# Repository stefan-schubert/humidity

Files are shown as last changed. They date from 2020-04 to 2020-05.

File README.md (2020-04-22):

# Humidity Monitoring Solution

The intention of the project is to monitor a ceiling cavity for critical humidity. This ceiling cavity is far away from any wlan hotspot. For that reason the system is divided in two units connected with RS485. The communication protocol used on top of RS485 is [PJON](https://www.pjon.org/). The sensor unit has a connection to 3 sensor pairs through I2C bus. The control unit has a buzzer, a display and a button. If humidity is to high the buzzer is activated until a normal value is reached again. The button deactivates the buzzer in the case of an error or enables or disables the display. The dispalay is automatically disabled after 10 minutes inactivity. For historical data recording and alerting the sensor data is submitted to [ubidots](https://ubidots.com/) through a MQTT connection connected over a wlan access point.

Take a look at the [photos](photos/)!

## Wiring

Sensor unit and control unit are connect through RS485 (A+, B+, GND connected with a cat. 5 patch cable wires).

### Sensor Unit

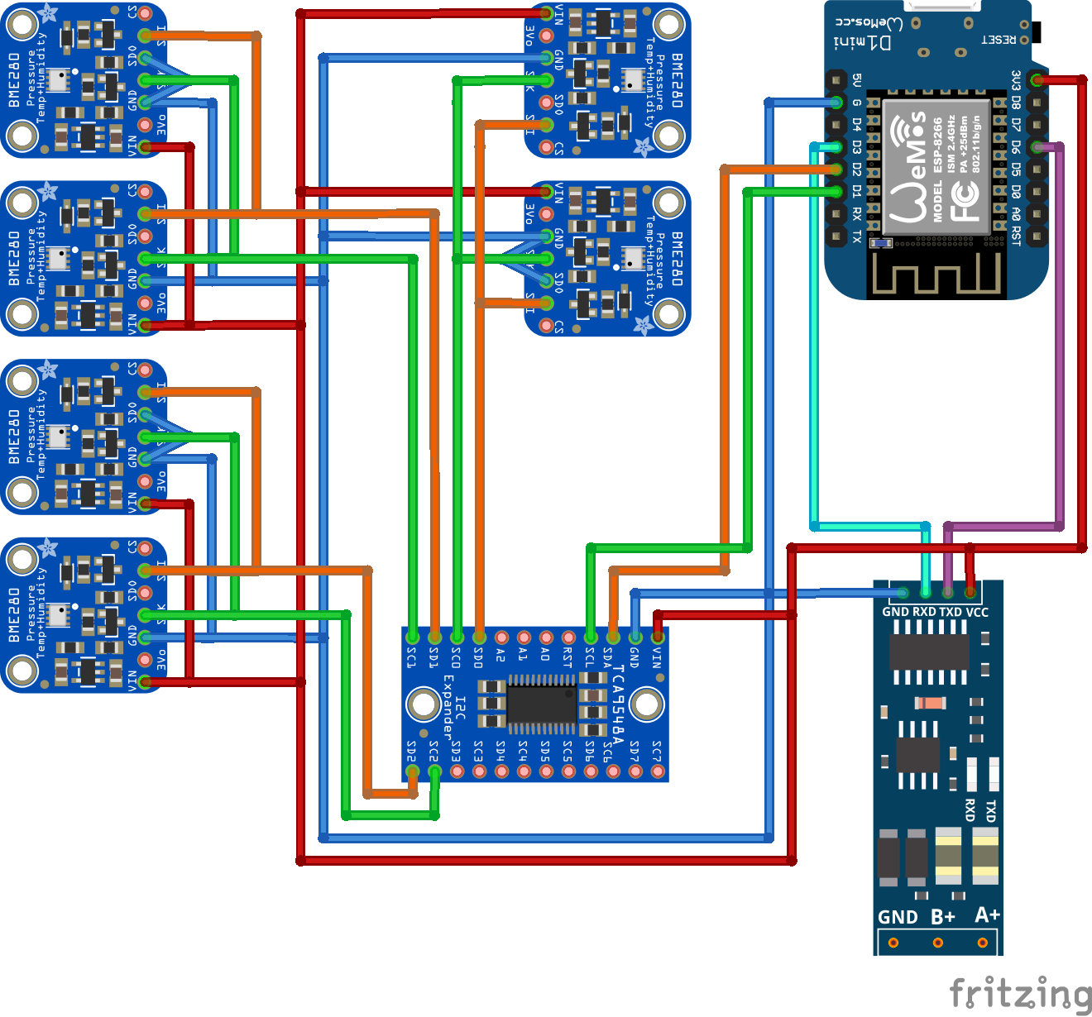
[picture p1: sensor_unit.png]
Sensor Unit


__Hardware Components__
* [Wemos D1 mini](https://www.wemos.cc/en/latest/d1/d1_mini.html)
* [TCA9548A 8-Channel I2C Switch](http://www.ti.com/lit/ds/symlink/tca9548a.pdf)
* [BME280 Pressure Module](https://startingelectronics.org/pinout/GY-BMP280-pressure-sensor-module/) 
  * Tutorials: [[1](https://startingelectronics.org/tutorials/arduino/modules/pressure-sensor/)] [[2](https://randomnerdtutorials.com/esp8266-bme280-arduino-ide/)] [[3](https://www.bluedot.space/tutorials/connect-two-bme280-on-i2c-bus/)] [[4](http://cactus.io/hookups/sensors/barometric/bme280/hookup-arduino-to-multiple-bme280-barometric-pressure-sensors)]
* [TTL RS485 Adapter](https://www.makershop.de/module/kommunikation-module/ttl-rs485-adapter/)
  * [Alternative](https://www.welectron.com/Waveshare-4777-RS485-Board-33V)

### Control Unit

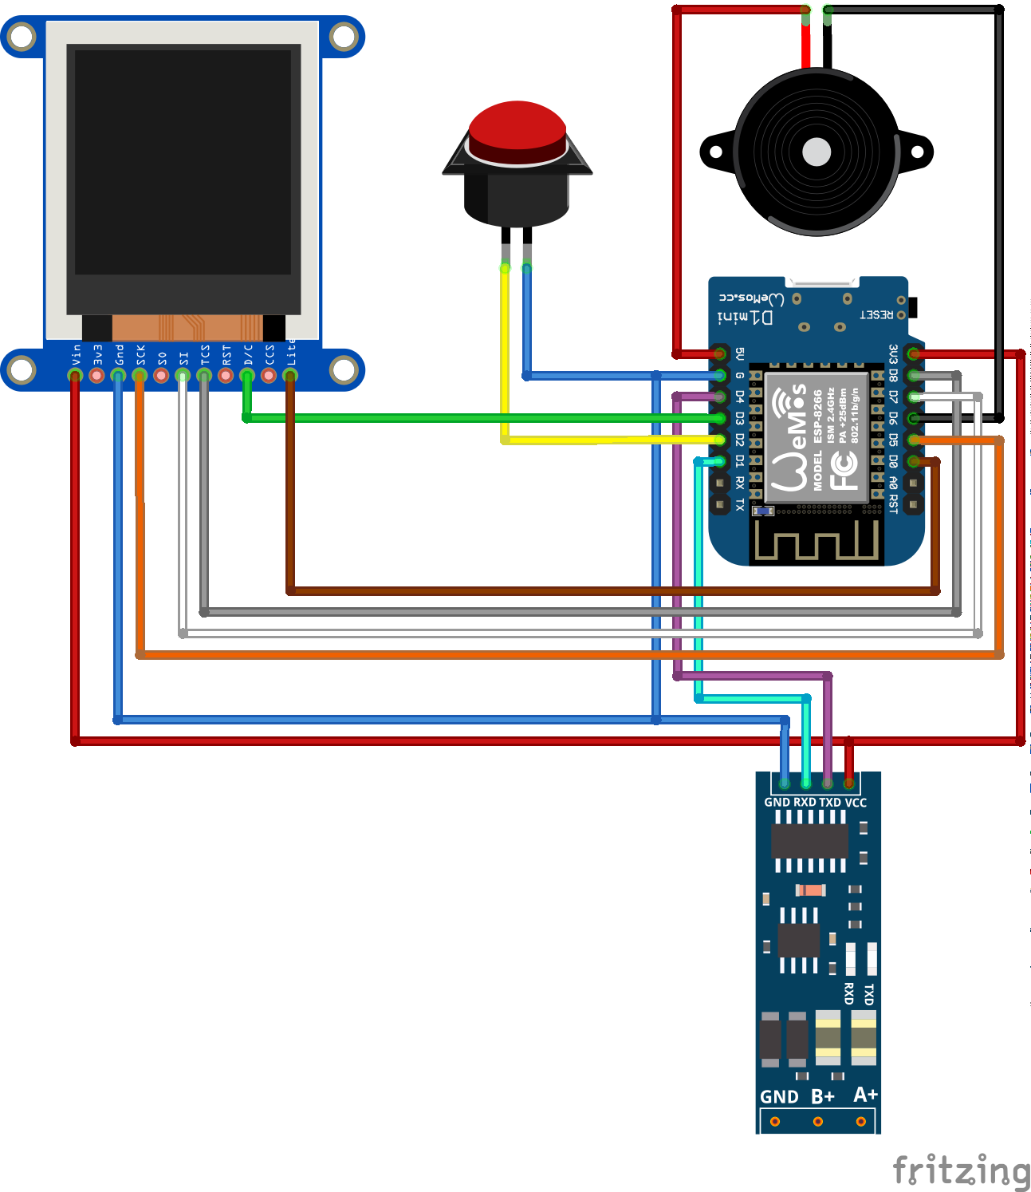
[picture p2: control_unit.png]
Control Unit


__Hardware Components__
* [WEMOS D1 mini](https://www.wemos.cc/en/latest/d1/d1_mini.html)
* [WEMOS TFT 1.4 Shield](https://www.wemos.cc/en/latest/d1_mini_shiled/tft_1_4.html)
* [WEMOS Buzzer Shield](https://www.wemos.cc/en/latest/d1_mini_shiled/buzzer.html)
* [TTL RS485 Adapter](https://www.makershop.de/module/kommunikation-module/ttl-rs485-adapter/)

## Libraries
* WEMOS D1 mini (ESP8266)
  * [5V tolerant?](https://www.ba0sh1.com/blog/2016/08/03/is-esp8266-io-really-5v-tolerant/)
  * Tutorials/Guides:
    * PINs: [[1](https://randomnerdtutorials.com/esp8266-pinout-reference-gpios/)] [[2](http://esp8266-server.de/wemos.html#Pinbelegung)]
    * [Safe Restart](https://github.com/esp8266/Arduino/issues/1722)
    * [WiFi](https://arduino-esp8266.readthedocs.io/en/latest/esp8266wifi/readme.html)
        * WPS [[1](https://www.az-delivery.de/blogs/azdelivery-blog-fur-arduino-und-raspberry-pi/wps-mit-dem-esp8266)] [[2](https://gist.github.com/copa2/fcc718c6549721c210d614a325271389)]
        * [MQTT Client](https://github.com/knolleary/pubsubclient)
        * [Cloud Storage Ubidots](https://ubidots.com/docs/hw/#mqtt)
    * ([DeepSleep](https://randomnerdtutorials.com/esp8266-deep-sleep-with-arduino-ide/))
* BME280 through I2C
    * [BME](https://github.com/finitespace/BME280)
    * [I2C](https://github.com/pasko-zh/brzo_i2c) (Fast Software BitBang written in assembly!)
        * [Interesting facts about I2C](https://www.i2c-bus.org/i2c-primer/analysing-obscure-problems/blocked-bus/)
* TFT
  * [Adafruit-ST7735-Library](https://github.com/adafruit/Adafruit-ST7735-Library/)
  * [U8g2_for_Adafruit_GFX](https://github.com/olikraus/U8g2_for_Adafruit_GFX)
    * [generate fonts](https://github.com/olikraus/u8g2/blob/master/doc/faq.txt#L179)
    * [generate icons](https://github.com/olikraus/u8g2/blob/master/tools/font/png2bdf/test/do_iconic.sh)
  * Examples
    * [Shield](https://github.com/wemos/D1_mini_Examples/tree/master/examples/04.Shields/TFT_1.4_Shield)
    * [Generate Colors](http://www.barth-dev.de/online/rgb565-color-picker/)
* RS485
  * no special library needed
  * Tutorials: [[1](https://maker.pro/arduino/tutorial/creating-long-distance-serial-communication-using-an-arduino-and-an-rs-485-module)] [[2](https://create.arduino.cc/projecthub/philippedc/arduino-esp8266-rs485-modbus-anemometer-45f1d8)] [[3](https://www.hackster.io/philippedc/arduino-esp8266-rs485-modbus-anemometer-45f1d8)] [[4](https://microcontrollerelectronics.com/sn75176-rs485-communications-between-two-arduinos/)] [[5](https://arduinoinfo.mywikis.net/wiki/SoftwareSerialRS485Example)]
  * [PJON](https://www.pjon.org) ([Github](https://github.com/gioblu/PJON)) as network protocol
    * Examples: [[1](https://github.com/gioblu/PJON/tree/master/src/strategies/ThroughSerialAsync)] [[2](https://www.pjon.org/data-reception.php)]
* Button
    * no special library needed
    * Tutorial: [[1](https://hikro.de/arduino-taster-als-schalter-programmieren)] [[2](https://www.arduino.cc/reference/en/language/functions/external-interrupts/attachinterrupt/)]

## Other sources
* [Fritzing parts](https://github.com/Warlib1975/Fritzing-parts)

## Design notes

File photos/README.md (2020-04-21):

# Photos

## Sensor Unit

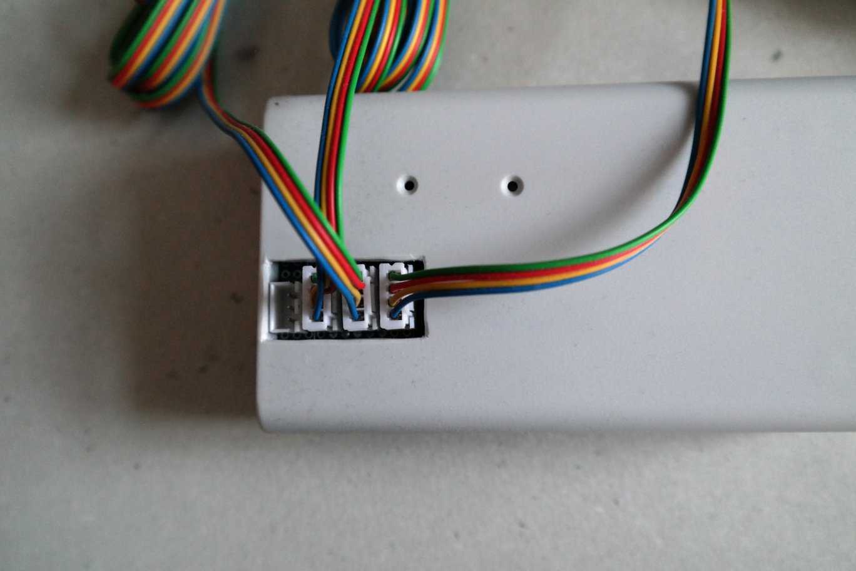
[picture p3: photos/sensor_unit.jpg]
sensor_unit


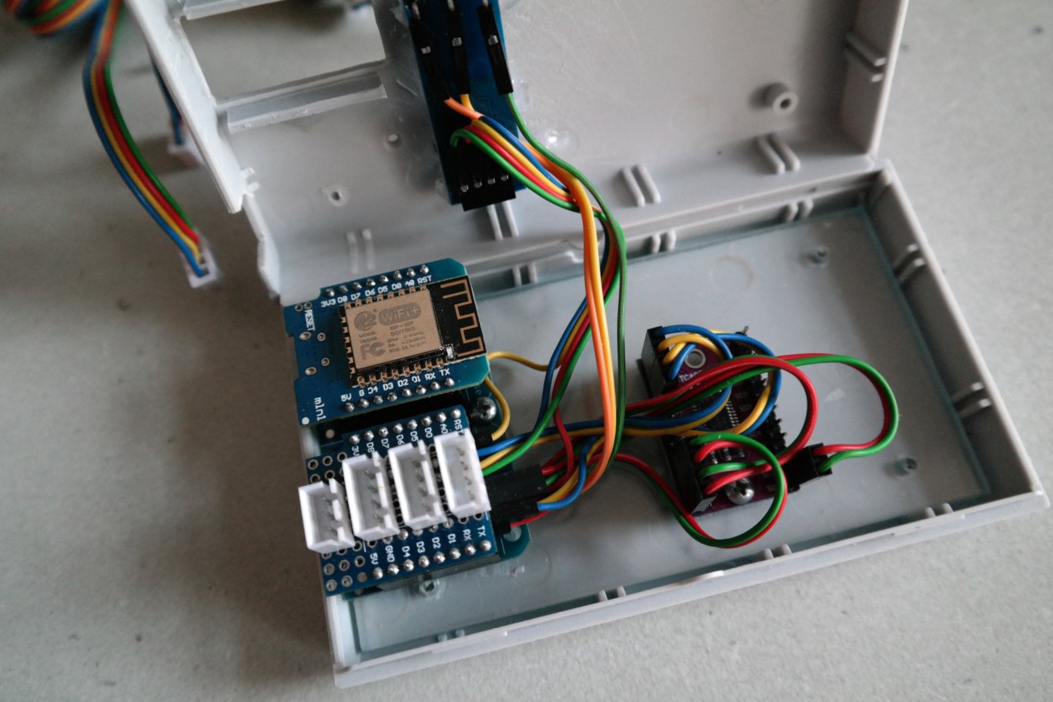
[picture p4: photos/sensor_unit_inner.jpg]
sensor_unit_inner


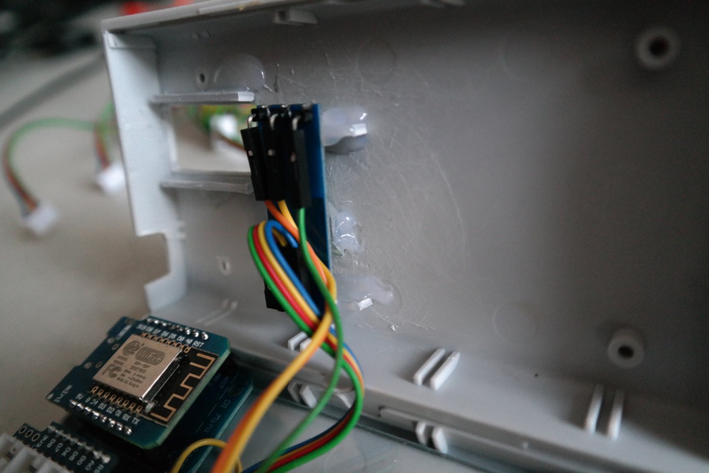
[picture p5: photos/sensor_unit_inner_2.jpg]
sensor_unit_inner_2


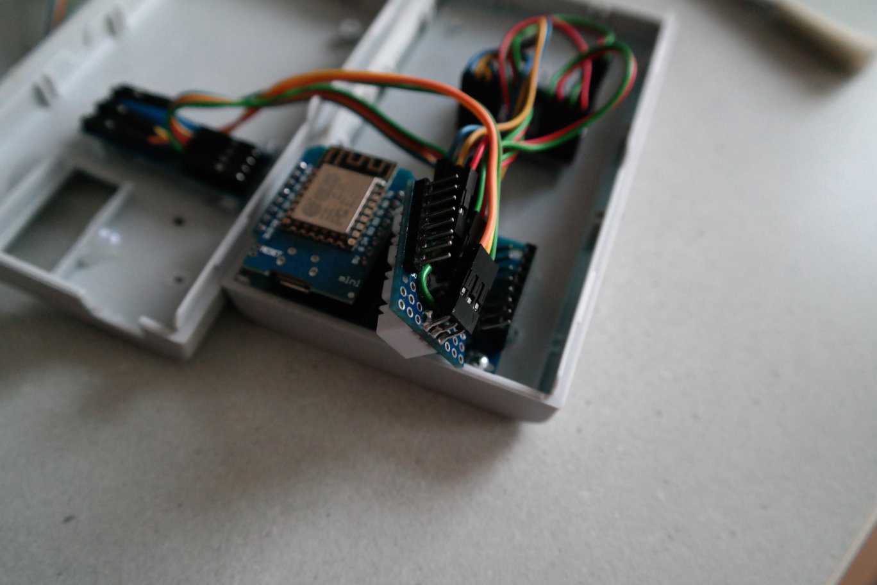
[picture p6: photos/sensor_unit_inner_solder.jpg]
sensor_unit_inner_solder


## Sensors

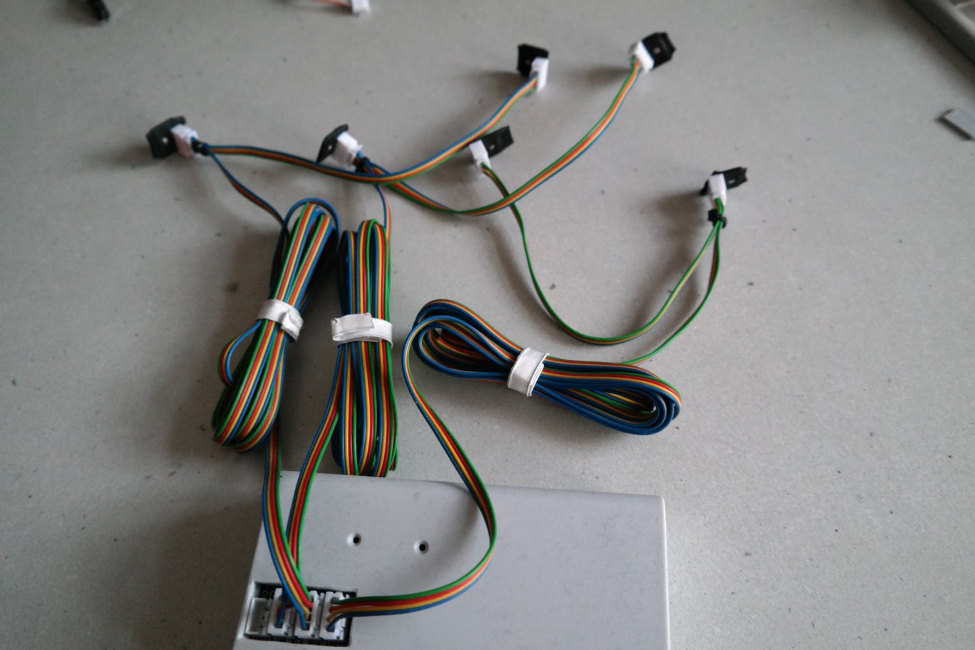
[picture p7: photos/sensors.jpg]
sensors


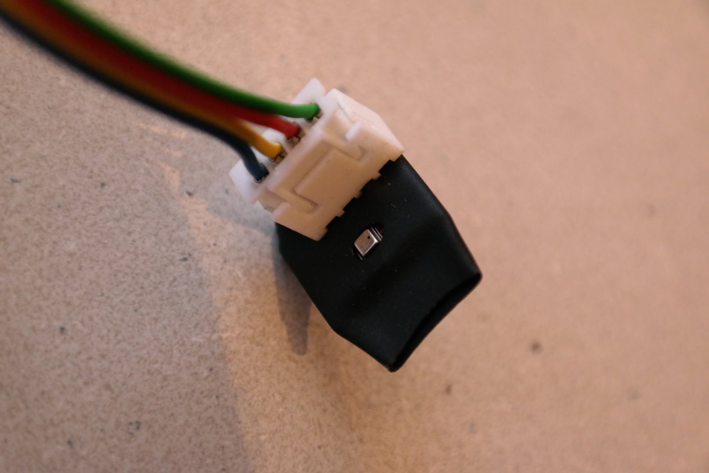
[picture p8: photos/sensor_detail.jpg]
sensor_detail


## Control Unit

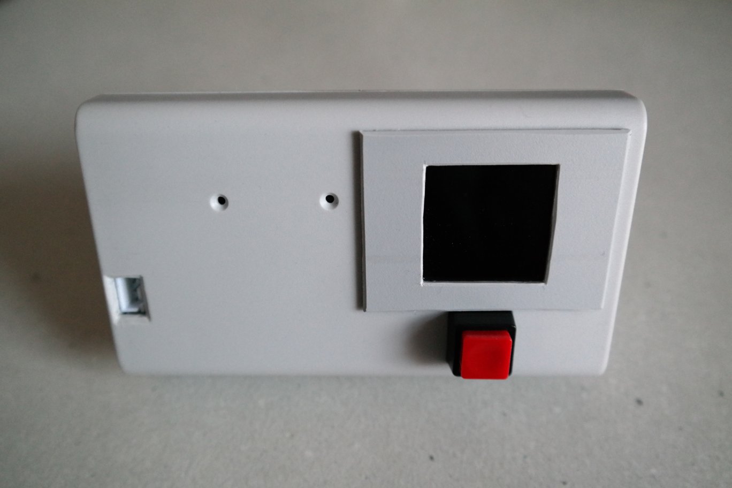
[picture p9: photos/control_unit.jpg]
control_unit


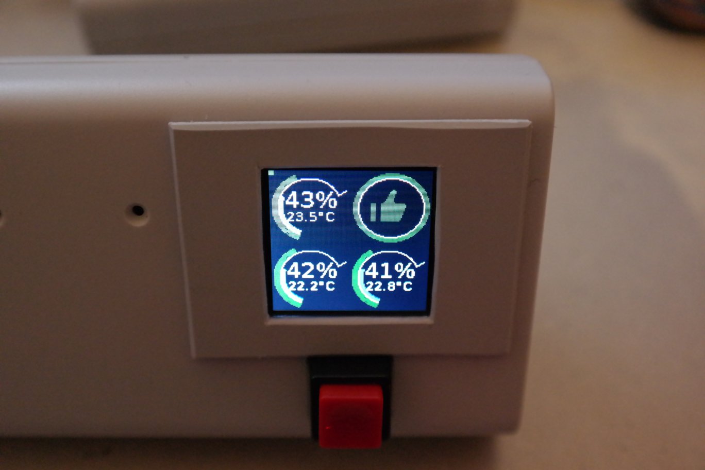
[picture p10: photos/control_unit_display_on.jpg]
control_unit_display_on


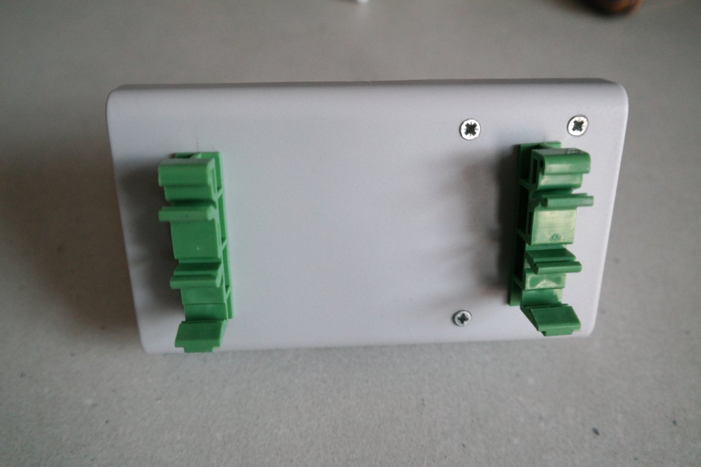
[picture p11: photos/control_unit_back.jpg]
control_unit_back


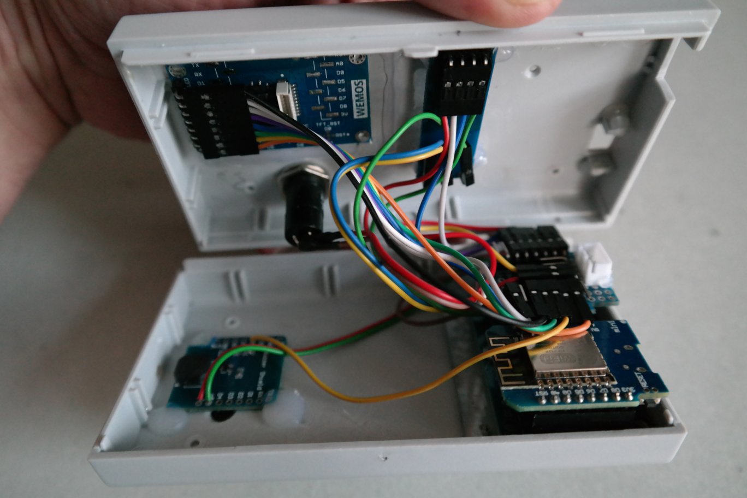
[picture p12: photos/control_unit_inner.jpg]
control_unit_inner


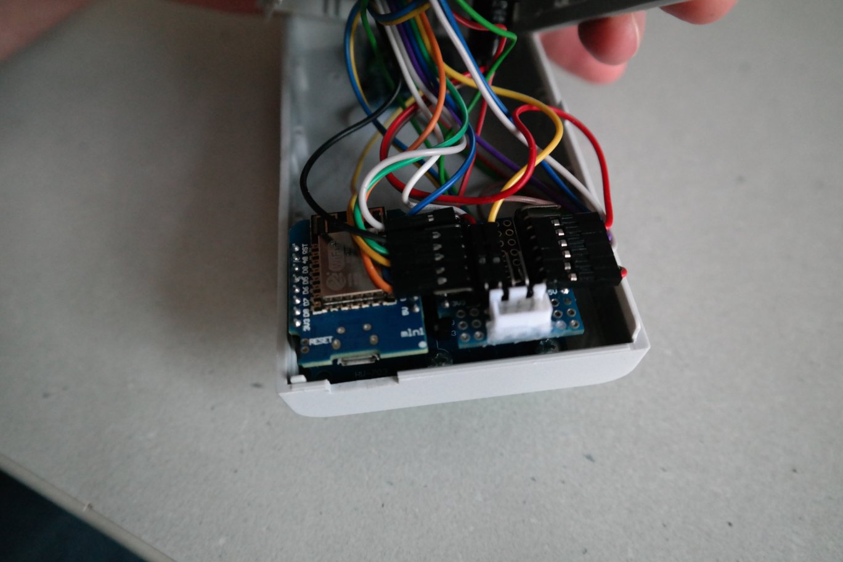
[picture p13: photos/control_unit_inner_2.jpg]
control_unit_inner_2


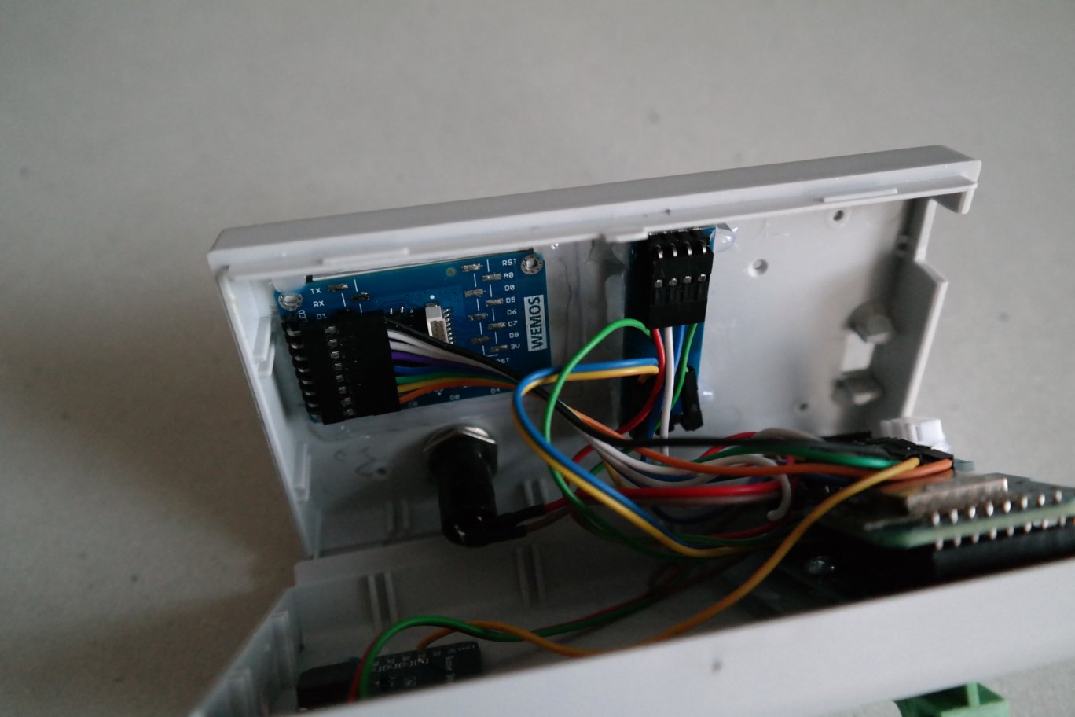
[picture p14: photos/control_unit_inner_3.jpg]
control_unit_inner_3


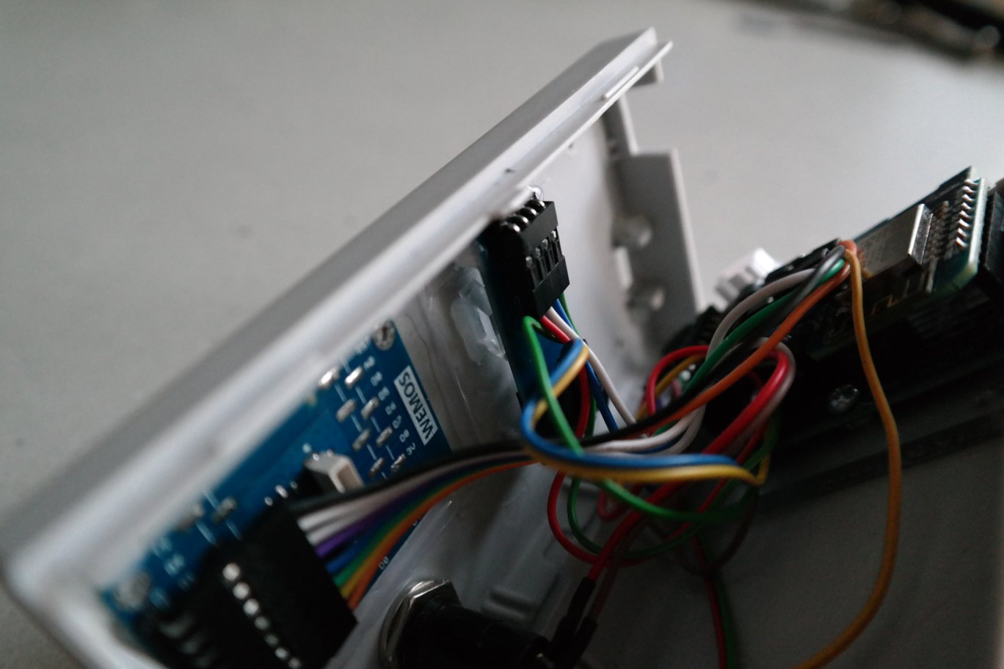
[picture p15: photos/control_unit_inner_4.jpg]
control_unit_inner_4


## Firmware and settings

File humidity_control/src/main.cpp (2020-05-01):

#define PJON_PACKET_MAX_LENGTH 32

#include <config.h>
#include <fonts.h>
#include <Arduino.h>
#include <ESP8266WiFi.h>
#include <time.h>
#include "SoftwareSerial.h"
#include "Wire.h"
#include "PJON.h"
#include "SPI.h"
#include "Adafruit_GFX.h"
#include "Adafruit_ST7735.h"
#include "U8g2_for_Adafruit_GFX.h"
#include "PubSubClient.h"

// DEBUG flag
// #define DEBUG

// pin config
#define RX_PIN D1
#define TX_PIN D4
#define ID 45
#define BUZZER_PIN D6
#define BUTTON_PIN D2
#define TFT_RST -1
#define TFT_CS D8
#define TFT_DC D3
#define TFT_LED D0

// colors
#define GREEN 0x34C0
#define YELLOW 0xFE60
#define RED 0xC980
#define BLUE 0x5E1B

// ubidots
#define SERVER "industrial.api.ubidots.com"
#define SERVER_PORT 8883

// constants
const unsigned int MAX_HUMIDITY = 70;                  // 70.00%
const unsigned int WARN_HUMIDITY = 50;                 // 50.00 %
const unsigned long MAX_AGE = 60000;                   // 1min
const unsigned long MAX_AGE_CLOUD = 300000;            // 5min
const unsigned long DEBOUNCE = 20;                     // 20ms
const unsigned long MAX_DISPLAY_ACTIVE = 600000;       // 10min
const unsigned long MAX_DISCONNECT_TIME = 600000;      // 10min
const unsigned long MAX_MQTT_DISCONNECT_TIME = 300000; // 5min
const uint8_t MAX_WIRES = 3;                           // max 3 sensor pairs
const unsigned int WARN_ANGLE = 110 + 320 * ((float)WARN_HUMIDITY / 100.0f);
const unsigned int ERROR_ANGLE = 110 + 320 * ((float)MAX_HUMIDITY / 100.0f);
// ca file
static const char *ca1 PROGMEM = "-----BEGIN CERTIFICATE-----\nMIIFazCCA1OgAwIBAgIRAIIQz7DSQONZRGPgu2OCiwAwDQYJKoZIhvcNAQELBQAw\nTzELMAkGA1UEBhMCVVMxKTAnBgNVBAoTIEludGVybmV0IFNlY3VyaXR5IFJlc2Vh\ncmNoIEdyb3VwMRUwEwYDVQQDEwxJU1JHIFJvb3QgWDEwHhcNMTUwNjA0MTEwNDM4\nWhcNMzUwNjA0MTEwNDM4WjBPMQswCQYDVQQGEwJVUzEpMCcGA1UEChMgSW50ZXJu\nZXQgU2VjdXJpdHkgUmVzZWFyY2ggR3JvdXAxFTATBgNVBAMTDElTUkcgUm9vdCBY\nMTCCAiIwDQYJKoZIhvcNAQEBBQADggIPADCCAgoCggIBAK3oJHP0FDfzm54rVygc\nh77ct984kIxuPOZXoHj3dcKi/vVqbvYATyjb3miGbESTtrFj/RQSa78f0uoxmyF+\n0TM8ukj13Xnfs7j/EvEhmkvBioZxaUpmZmyPfjxwv60pIgbz5MDmgK7iS4+3mX6U\nA5/TR5d8mUgjU+g4rk8Kb4Mu0UlXjIB0ttov0DiNewNwIRt18jA8+o+u3dpjq+sW\nT8KOEUt+zwvo/7V3LvSye0rgTBIlDHCNAymg4VMk7BPZ7hm/ELNKjD+Jo2FR3qyH\nB5T0Y3HsLuJvW5iB4YlcNHlsdu87kGJ55tukmi8mxdAQ4Q7e2RCOFvu396j3x+UC\nB5iPNgiV5+I3lg02dZ77DnKxHZu8A/lJBdiB3QW0KtZB6awBdpUKD9jf1b0SHzUv\nKBds0pjBqAlkd25HN7rOrFleaJ1/ctaJxQZBKT5ZPt0m9STJEadao0xAH0ahmbWn\nOlFuhjuefXKnEgV4We0+UXgVCwOPjdAvBbI+e0ocS3MFEvzG6uBQE3xDk3SzynTn\njh8BCNAw1FtxNrQHusEwMFxIt4I7mKZ9YIqioymCzLq9gwQbooMDQaHWBfEbwrbw\nqHyGO0aoSCqI3Haadr8faqU9GY/rOPNk3sgrDQoo//fb4hVC1CLQJ13hef4Y53CI\nrU7m2Ys6xt0nUW7/vGT1M0NPAgMBAAGjQjBAMA4GA1UdDwEB/wQEAwIBBjAPBgNV\nHRMBAf8EBTADAQH/MB0GA1UdDgQWBBR5tFnme7bl5AFzgAiIyBpY9umbbjANBgkq\nhkiG9w0BAQsFAAOCAgEAVR9YqbyyqFDQDLHYGmkgJykIrGF1XIpu+ILlaS/V9lZL\nubhzEFnTIZd+50xx+7LSYK05qAvqFyFWhfFQDlnrzuBZ6brJFe+GnY+EgPbk6ZGQ\n3BebYhtF8GaV0nxvwuo77x/Py9auJ/GpsMiu/X1+mvoiBOv/2X/qkSsisRcOj/KK\nNFtY2PwByVS5uCbMiogziUwthDyC3+6WVwW6LLv3xLfHTjuCvjHIInNzktHCgKQ5\nORAzI4JMPJ+GslWYHb4phowim57iaztXOoJwTdwJx4nLCgdNbOhdjsnvzqvHu7Ur\nTkXWStAmzOVyyghqpZXjFaH3pO3JLF+l+/+sKAIuvtd7u+Nxe5AW0wdeRlN8NwdC\njNPElpzVmbUq4JUagEiuTDkHzsxHpFKVK7q4+63SM1N95R1NbdWhscdCb+ZAJzVc\noyi3B43njTOQ5yOf+1CceWxG1bQVs5ZufpsMljq4Ui0/1lvh+wjChP4kqKOJ2qxq\n4RgqsahDYVvTH9w7jXbyLeiNdd8XM2w9U/t7y0Ff/9yi0GE44Za4rF2LN9d11TPA\nmRGunUHBcnWEvgJBQl9nJEiU0Zsnvgc/ubhPgXRR4Xq37Z0j4r7g1SgEEzwxA57d\nemyPxgcYxn/eR44/KJ4EBs+lVDR3veyJm+kXQ99b21/+jh5Xos1AnX5iItreGCc=\n-----END CERTIFICATE-----\n";
static const char *ca2 PROGMEM = "-----BEGIN CERTIFICATE-----\nMIIDSjCCAjKgAwIBAgIQRK+wgNajJ7qJMDmGLvhAazANBgkqhkiG9w0BAQUFADA/\nMSQwIgYDVQQKExtEaWdpdGFsIFNpZ25hdHVyZSBUcnVzdCBDby4xFzAVBgNVBAMT\nDkRTVCBSb290IENBIFgzMB4XDTAwMDkzMDIxMTIxOVoXDTIxMDkzMDE0MDExNVow\nPzEkMCIGA1UEChMbRGlnaXRhbCBTaWduYXR1cmUgVHJ1c3QgQ28uMRcwFQYDVQQD\nEw5EU1QgUm9vdCBDQSBYMzCCASIwDQYJKoZIhvcNAQEBBQADggEPADCCAQoCggEB\nAN+v6ZdQCINXtMxiZfaQguzH0yxrMMpb7NnDfcdAwRgUi+DoM3ZJKuM/IUmTrE4O\nrz5Iy2Xu/NMhD2XSKtkyj4zl93ewEnu1lcCJo6m67XMuegwGMoOifooUMM0RoOEq\nOLl5CjH9UL2AZd+3UWODyOKIYepLYYHsUmu5ouJLGiifSKOeDNoJjj4XLh7dIN9b\nxiqKqy69cK3FCxolkHRyxXtqqzTWMIn/5WgTe1QLyNau7Fqckh49ZLOMxt+/yUFw\n7BZy1SbsOFU5Q9D8/RhcQPGX69Wam40dutolucbY38EVAjqr2m7xPi71XAicPNaD\naeQQmxkqtilX4+U9m5/wAl0CAwEAAaNCMEAwDwYDVR0TAQH/BAUwAwEB/zAOBgNV\nHQ8BAf8EBAMCAQYwHQYDVR0OBBYEFMSnsaR7LHH62+FLkHX/xBVghYkQMA0GCSqG\nSIb3DQEBBQUAA4IBAQCjGiybFwBcqR7uKGY3Or+Dxz9LwwmglSBd49lZRNI+DT69\nikugdB/OEIKcdBodfpga3csTS7MgROSR6cz8faXbauX+5v3gTt23ADq1cEmv8uXr\nAvHRAosZy5Q6XkjEGB5YGV8eAlrwDPGxrancWYaLbumR9YbK+rlmM6pZW87ipxZz\nR8srzJmwN0jP41ZL9c8PDHIyh8bwRLtTcm1D9SZImlJnt1ir/md2cXjbDaJWFBM5\nJDGFoqgCWjBH4d1QB7wCCZAA62RjYJsWvIjJEubSfZGL+T0yjWW06XyxV3bqxbYo\nOb8VZRzI9neWagqNdwvYkQsEjgfbKbYK7p2CNTUQ\n-----END CERTIFICATE-----\n";
BearSSL::X509List x509;

// display
Adafruit_ST7735 tft = Adafruit_ST7735(TFT_CS, TFT_DC, TFT_RST);
U8G2_FOR_ADAFRUIT_GFX u8g2;
// serial port for PJON
SoftwareSerial port;
PJON<ThroughSerialAsync> bus(ID);
// secure wifi connection client
WiFiClientSecure client;
// client
PubSubClient mqtt(SERVER, SERVER_PORT, client);

// PJON data structure
struct sensor
{
  uint16_t humidity;
  uint16_t temperature;
  bool connected_0;
  bool connected_1;
};
struct sensor_record
{
  sensor sensors[MAX_WIRES];
};
// status of system
enum status
{
  ERROR,
  WARN,
  NORMAL,
  OUTDATED,
  NONE,
  INIT
};
// cache data structure
struct cache_entry
{
  bool fresh;
  bool value_available;
  uint16_t humidity;
  double temperature;
};
struct cache
{
  cache_entry entries[MAX_WIRES];
};

// timers
unsigned long last_time_button_pressed = millis();
unsigned long last_time_payload_recieved = millis();
unsigned long last_time_display_active = millis();
unsigned long last_time_data_submitted = millis();
unsigned long last_time_tried_to_reconnect = 0;
// flags
volatile bool data_cleared = false;
volatile bool buttonPressed = false;
volatile bool buzzer_active = false;
volatile bool error_active = false;
volatile bool display_active = true;
bool initial_connection_status = false;
// status
status last_status = INIT;
// record
sensor_record record = {.sensors = {{.humidity = 0, .temperature = 0, .connected_0 = false, .connected_1 = false}, {.humidity = 0, .temperature = 0, .connected_0 = false, .connected_1 = false}, {.humidity = 0, .temperature = 0, .connected_0 = false, .connected_1 = false}}};
// cache
cache cache_instance = {.entries = {{.fresh = true}, {.fresh = true}, {.fresh = true}}};

/**
 * Toggles display on or off.
 * 
 * @param on_off display state, true == on
 */
void toggleDisplay(bool on_off)
{
  last_time_display_active = millis();
  if (display_active == on_off)
  {
    return;
  }
  display_active = on_off;
  tft.enableDisplay(on_off);
  digitalWrite(TFT_LED, on_off ? HIGH : LOW);
}

/**
 * Draws an arc on given coordinate.
 */
void drawArc(uint16_t x, uint16_t y, int start_angle, int end_angle, uint16_t radius, uint16_t thinkness, uint16_t color)
{
  for (int i = start_angle; i <= end_angle; i++)
  {
    double rad_inner = i * DEG_TO_RAD;
    double rad_outer0 = (i == start_angle ? i : i - 1) * DEG_TO_RAD;
    double rad_outer1 = (i == end_angle ? i : i + 1) * DEG_TO_RAD;
    uint16_t outer_radius = radius + thinkness;
    double x0 = (cos(rad_inner) * radius) + x;
    double y0 = (sin(rad_inner) * radius) + y;
    double x1 = (cos(rad_outer0) * outer_radius) + x;
    double y1 = (sin(rad_outer0) * outer_radius) + y;
    double x2 = (cos(rad_outer1) * outer_radius) + x;
    double y2 = (sin(rad_outer1) * outer_radius) + y;
    tft.drawTriangle(x0, y0, x1, y1, x2, y2, color);
  }
}

/**
 * Draws a gauge at specified coordinate.
 */
void drawGauge(uint16_t x, uint16_t y, sensor *sensor, cache_entry *cache)
{
  // normal 0-50, warn 51-70, error 71-100
  uint16_t h = round((double)sensor->humidity / 100.0);
  h = h < 100 ? h : 100;
  double t = (double)(sensor->temperature / 10) / 10.0;
  t = t < 80.0 ? t : 80.0;
  bool value_available = sensor->connected_0 || sensor->connected_0;
  bool force_update = !cache->value_available && cache->value_available != value_available;
  bool force_reset = !value_available && value_available != cache->value_available;

  // 360-40 = 320
  // draw humidity
  if (cache->fresh || force_update || (h != cache->humidity && value_available))
  {
    uint16_t degrees = round(h * 3.2) + 110;
    if (h > 0 && h <= WARN_HUMIDITY)
    {
      drawArc(x, y, 110, degrees, 26, 4, GREEN);
    }
    else if (h > WARN_HUMIDITY && h <= MAX_HUMIDITY)
    {
      drawArc(x, y, 110, WARN_ANGLE, 26, 4, GREEN);
      drawArc(x, y, WARN_ANGLE + 1, degrees, 26, 4, YELLOW);
    }
    else if (h > MAX_HUMIDITY)
    {
      drawArc(x, y, 110, WARN_ANGLE, 26, 4, GREEN);
      drawArc(x, y, WARN_ANGLE + 1, ERROR_ANGLE, 26, 4, YELLOW);
      drawArc(x, y, ERROR_ANGLE + 1, degrees, 26, 4, RED);
    }
    drawArc(x, y, degrees + (degrees > 0 && degrees < 430 ? 1 : 0), 430, 26, 4, ST7735_BLACK);
    drawArc(x, y, ERROR_ANGLE, ERROR_ANGLE, 25, 7, ST7735_WHITE);
  }
  // reset gauge
  if (force_reset)
  {
    drawArc(x, y, 110, 430, 26, 4, ST7735_BLACK);
    drawArc(x, y, ERROR_ANGLE, ERROR_ANGLE, 25, 7, ST7735_WHITE);
  }

  // draw temperature
  if (cache->fresh || force_update || (t != cache->temperature && value_available))
  {
    uint16_t degrees = round(t * 4) + 110;
    drawArc(x, y, 110, degrees, 22, 2, BLUE);
    drawArc(x, y, degrees + (degrees > 0 && degrees < 430 ? 1 : 0), 430, 22, 2, ST7735_BLACK);
  }
  // reset gauge
  if (force_reset)
  {
    drawArc(x, y, 110, 430, 22, 2, ST7735_BLACK);
  }

  // write numbers
  if (cache->fresh || force_update || force_reset || h != cache->humidity || t != cache->temperature)
  {
    tft.fillCircle(x, y, 21, ST7735_BLACK);
    u8g2.setForegroundColor(ST7735_WHITE);
    char h_string[4] = "--%";
    if (h > 0 && value_available)
    {
      sprintf(h_string, "%3d%%", h);
    }
    u8g2.setFont(dejavu_14);
    u8g2.drawUTF8(x - u8g2.getUTF8Width(h_string) / 2, y, h_string);

    u8g2.setForegroundColor(ST7735_WHITE);
    char t_string[8] = "--°C";
    if (t > 0 && value_available)
    {
      sprintf(t_string, "%3.1f°C", t);
    }
    u8g2.setFont(dejavu_8);
    u8g2.drawUTF8(x - u8g2.getUTF8Width(t_string) / 2, y + 12, t_string);
  }

  // draw max value
  if (cache->fresh)
  {
    drawArc(x, y, 110, 333, 25, 0, ST7735_WHITE);
  }

  // set values in cache
  cache->value_available = value_available;
  cache->fresh = false;
  cache->humidity = h;
  cache->temperature = t;
}

/**
 * Draws a status as icon.
 */
void drawStatus(uint16_t x, uint16_t y, status s, status *last_status)
{
  status last = *last_status;
  if (last != s)
  {
    switch (s)
    {
    case ERROR:
      tft.fillCircle(x, y, 30, RED);
      tft.fillCircle(x, y, 26, ST7735_BLACK);
      tft.drawCircle(x, y, 26, ST7735_WHITE);
      u8g2.setFont(open_iconic_symbols_4x);
      u8g2.setForegroundColor(BLUE);
      u8g2.drawGlyph(x - 16, y + 16, 67);
      break;
    case WARN:
      tft.fillCircle(x, y, 30, YELLOW);
      tft.fillCircle(x, y, 26, ST7735_BLACK);
      tft.drawCircle(x, y, 26, ST7735_WHITE);
      u8g2.setFont(open_iconic_symbols_4x);
      u8g2.setForegroundColor(YELLOW);
      u8g2.drawGlyph(x - 14, y + 14, 66);
      break;
    case NORMAL:
      tft.fillCircle(x, y, 30, GREEN);
      tft.fillCircle(x, y, 26, ST7735_BLACK);
      tft.drawCircle(x, y, 26, ST7735_WHITE);
      u8g2.setFont(open_iconic_symbols_4x);
      u8g2.setForegroundColor(GREEN);
      u8g2.drawGlyph(x - 16, y + 16, 65);
      break;
    case OUTDATED:
      tft.fillCircle(x, y, 30, ST7735_BLACK);
      tft.drawCircle(x, y, 26, ST7735_WHITE);
      u8g2.setFont(open_iconic_symbols_4x);
      u8g2.setForegroundColor(ST7735_WHITE);
      u8g2.drawGlyph(x - 16, y + 16, 64);
      break;
    default:
      tft.fillCircle(x, y, 30, ST7735_BLACK);
      tft.drawCircle(x, y, 26, ST7735_WHITE);
      break;
    }
  }
  *last_status = s;
}

/**
 * Checks record for new status by checking values against configured threshold.
 */
void checkStatusAndDrawValues(sensor_record *record)
{
  last_time_payload_recieved = millis();
  if (data_cleared)
  {
    toggleDisplay(true);
  }
  data_cleared = false;
  uint16_t max_humidity = 0;
  for (uint8_t i = 0; i < MAX_WIRES; i++)
  {
    if (record->sensors[i].humidity > max_humidity)
    {
      max_humidity = record->sensors[i].humidity;
    }
  }
  if (max_humidity > MAX_HUMIDITY * 100 && !error_active)
  {
#ifdef DEBUG
    Serial.println("Humidity to high: Turn on the buzzer!");
#endif
    toggleDisplay(true);
    error_active = true;
    buzzer_active = true;
    tone(BUZZER_PIN, 1480.0);
    drawStatus(96, 32, ERROR, &last_status);
  }
  else if (max_humidity > WARN_HUMIDITY * 100 && max_humidity <= MAX_HUMIDITY * 100)
  {
    noTone(BUZZER_PIN);
    drawStatus(96, 32, WARN, &last_status);
  }
  else if (max_humidity > 0 && max_humidity <= WARN_HUMIDITY * 100)
  {
    noTone(BUZZER_PIN);
    drawStatus(96, 32, NORMAL, &last_status);
  }
  if (error_active && max_humidity <= MAX_HUMIDITY * 100)
  {
    error_active = false;
  }
  drawGauge(32, 32, &record->sensors[0], &cache_instance.entries[0]);
  drawGauge(32, 96, &record->sensors[1], &cache_instance.entries[1]);
  drawGauge(96, 96, &record->sensors[2], &cache_instance.entries[2]);
}

/**
 * Connects MQTT
 */
bool connectMQTT()
{
  // Stop if already connected.
  if (mqtt.connected())
  {
    return true;
  }

#ifdef DEBUG
  Serial.println("Connecting to MQTT... ");
#endif

  bool result = mqtt.connect("humidity_device", TOKEN, "");
  if (!result)
  {
#ifdef DEBUG
    Serial.println(mqtt.state());
    Serial.println("MQTT not connected!");
#endif
    mqtt.disconnect();
    // set connection status
    tft.fillRect(0, 0, 4, 4, YELLOW);
    return false;
  }

#ifdef DEBUG
  Serial.println("MQTT connected!");
#endif

  // set connection status
  tft.fillRect(0, 0, 4, 4, GREEN);
  return true;
}

/**
 * Submits values to mqtt broker.
 */
void submitValues(sensor_record *record)
{
  long current_millis = millis();
  if (initial_connection_status && (current_millis - last_time_data_submitted) > MAX_AGE_CLOUD && mqtt.connected() && mqtt.state() == MQTT_CONNECTED)
  {
    last_time_data_submitted = current_millis;
#ifdef DEBUG
    Serial.println("Submit data!");
#endif

    // build topic and payload
    char payload[50];
    char *payload_ptr = payload;
    bool has_payload = false;
    for (uint8_t i = 0; i < MAX_WIRES; i++)
    {
      if (record->sensors[i].connected_0 || record->sensors[i].connected_1)
      {
        payload_ptr += sprintf(payload_ptr, "%s\"h%d\":%3.2f,\"t%d\":%3.2f", has_payload ? "," : "", i, record->sensors[i].humidity / 100.0, i, record->sensors[i].temperature / 100.0);
        has_payload = true;
      }
    }
    if (has_payload)
    {
      char wrapped[50];
      sprintf(wrapped, "{%s}", payload);
#ifdef DEBUG
      Serial.println(wrapped);
#endif
      // publish data
      mqtt.publish(TOPIC, wrapped);
    }
#ifdef DEBUG
    Serial.printf("Free space: [%d]\n", ESP.getFreeHeap());
#endif
  }
#ifdef DEBUG
  if (mqtt.state() != MQTT_CONNECTED)
  {
    Serial.println("MQTT Connection lost!");
  }
#endif
}

/**
 * Payload handler for PJON.
 */
void payloadHandler(uint8_t *payload, uint16_t length, const PJON_Packet_Info &packet_info)
{
  memcpy(&record, payload, sizeof(record));
  // handler data
  checkStatusAndDrawValues(&record);
  // send data to the cloud
  submitValues(&record);
#ifdef DEBUG
  for (uint8_t i = 0; i < MAX_WIRES; i++)
  {
    Serial.printf("Recieved: hum %u; temp %u; s0 %u; s1 %u\n", record.sensors[i].humidity, record.sensors[i].temperature, record.sensors[i].connected_0, record.sensors[i].connected_1);
  }
#endif
}

/**
 * Error handler for PJON.
 */
void errorHandler(uint8_t code, uint16_t data, void *custom_pointer)
{
  if (code == PJON_CONNECTION_LOST)
  {
    digitalWrite(LED_BUILTIN, HIGH);
#ifdef DEBUG
    Serial.println("Error!");
#endif
  }
}

/**
 * Button interupt handler. 
 * 
 * Turns on display, if display is off and now error is present.
 * If error is present, button pressed deactivates buzzer.
 */
void ICACHE_RAM_ATTR buttonPress()
{
  if ((millis() - last_time_button_pressed) > DEBOUNCE)
  {
    if (buttonPressed == false)
    {
      buttonPressed = true;
      if (!buzzer_active)
      {
        toggleDisplay(!display_active);
      }
      buzzer_active = false;
      noTone(BUZZER_PIN);
    }
    else
    {
      buttonPressed = false;
    }
    last_time_button_pressed = millis();
  }
}

/**
 * Init wifi.
 */
bool initWifi()
{
  WiFi.mode(WIFI_STA);
#ifdef DEBUG
  Serial.printf("Stored SSID: [%s]\n", WiFi.SSID().c_str());
#endif
  if (strlen(WiFi.SSID().c_str()) > 0)
  {
    WiFi.begin(WiFi.SSID().c_str(), WiFi.psk().c_str());
  }
  else
  {
    WiFi.begin(DEFAULT_WLAN_SSID, DEFAULT_WLAN_KEY);
  }
  uint8_t count = 0;
  while (WiFi.status() != WL_CONNECTED && count < 100)
  {
    delay(500);
    count++;
  }

  if (WiFi.status() == WL_CONNECTED)
  {
    return true;
  }
  else
  {
    delay(10000);
    // start wps
    if (WiFi.beginWPSConfig() && WiFi.SSID().length() > 0)
    {
      return true;
    }
    else
    {
      return false;
#ifdef DEBUG
      Serial.println("WPS failed!");
#endif
    }
  }
}

/**
 * Setup system.
 */
void setup()
{
  delay(2000);
#ifdef DEBUG
  Serial.begin(9600);
  Serial.setDebugOutput(true);
#endif

  // setup TFT backlight pin
  pinMode(TFT_LED, OUTPUT);
  digitalWrite(TFT_LED, HIGH);

  // init TFT
  tft.initR(INITR_144GREENTAB);
  // use u8g2
  u8g2.begin(tft);
  u8g2.setForegroundColor(ST7735_WHITE);
  tft.setRotation(tft.getRotation() + 1);
  tft.fillScreen(ST7735_BLACK);

  // draw status and gauges
  drawStatus(96, 32, NONE, &last_status);
  drawGauge(32, 32, &record.sensors[0], &cache_instance.entries[0]);
  drawGauge(32, 96, &record.sensors[0], &cache_instance.entries[1]);
  drawGauge(96, 96, &record.sensors[0], &cache_instance.entries[2]);

  // start software serial port
  port.begin(9600, SWSERIAL_8N1, RX_PIN, TX_PIN, false);

  // setup PJON
  bus.strategy.set_serial(&port);
  // set handlers
  bus.set_error(errorHandler);
  bus.set_receiver(payloadHandler);
  // start bus
  bus.begin();

  // setup button pin
  pinMode(BUTTON_PIN, INPUT_PULLUP);
  // connect to interrupt
  attachInterrupt(digitalPinToInterrupt(BUTTON_PIN), buttonPress, CHANGE);

  // init wifi
  initial_connection_status = initWifi();
  // set connection status
  tft.fillRect(0, 0, 4, 4, initial_connection_status ? GREEN : RED);
  if (initial_connection_status)
  {
    // init mqtt
    configTime(1 * 3600, 0, "de.pool.ntp.org");
    delay(2000);
    x509.append(ca1);
    x509.append(ca2);
    client.setTrustAnchors(&x509);
    connectMQTT();
  }

#ifdef DEBUG
  Serial.println("Init complete!");
#endif
}

/**
 * Event loop.
 */
void loop()
{
  // trigger PJON handlers
  bus.update();
  bus.receive();
  // trigger mqtt handlers
  if (initial_connection_status)
  {
    mqtt.loop();
  }

  unsigned long current_millis = millis();
  // turn on display and show cleared status if no new data has been received
  if (!data_cleared && (current_millis - last_time_payload_recieved) > MAX_AGE)
  {
    toggleDisplay(true);
    drawStatus(96, 32, OUTDATED, &last_status);
    for (uint8_t i = 0; i < MAX_WIRES; i++)
    {
      record.sensors[i].connected_0 = false;
      record.sensors[i].connected_1 = false;
    }
    drawGauge(32, 32, &record.sensors[0], &cache_instance.entries[0]);
    drawGauge(32, 96, &record.sensors[1], &cache_instance.entries[1]);
    drawGauge(96, 96, &record.sensors[2], &cache_instance.entries[2]);
    data_cleared = true;
  }

  // turn off backlight if no error is present, backlight is on and display timeout is reached
  if (!error_active && display_active && (current_millis - last_time_display_active) > MAX_DISPLAY_ACTIVE)
  {
    toggleDisplay(false);
  }

  // check connection status
  if (initial_connection_status && !mqtt.connected())
  {
    if (WiFi.status() == WL_CONNECTED)
    {
      // connect to mqtt broker
      if ((current_millis - last_time_tried_to_reconnect) > MAX_MQTT_DISCONNECT_TIME)
      {
        last_time_tried_to_reconnect = current_millis;
        if (connectMQTT())
        {
          last_time_tried_to_reconnect = 0;
        }
      }
      else
      {
        // set connection status
        tft.fillRect(0, 0, 4, 4, YELLOW);
      }
    }
    else
    {
      // set connection status
      tft.fillRect(0, 0, 4, 4, RED);
    }
  }

  // restart machine, if we are not connected
  if (initial_connection_status && WiFi.status() != WL_CONNECTED && (current_millis - last_time_data_submitted) > MAX_DISCONNECT_TIME)
  {
    WiFi.forceSleepBegin();
    wdt_reset();
    ESP.restart();
    while (1)
    {
      wdt_reset();
    }
  }
}

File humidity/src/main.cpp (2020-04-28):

#define PJON_PACKET_MAX_LENGTH 32

#include <Arduino.h>
#include "brzo_i2c.h"
#include <BME280_BRZO.h>
#include "SoftwareSerial.h"
#include "PJON.h"

// DEBUG flag
// #define DEBUG

// pin config
#define SDA D2
#define SCL D1
#define RX_PIN D3
#define TX_PIN D6

// multiplexer address
#define TCAADDR 0x70
// PJON id
#define ID 44

// constants
// check interval to read sensor values
const unsigned long CHECK_INTERVAL = 10000; // 10s
// max sensor wires connected to multiplexer
// each wire has 2 sensors
const uint8_t MAX_WIRES = 3;
// last measured time
unsigned long lastTime = millis();
// serial port for PJON
SoftwareSerial port;
// PJON instance
PJON<ThroughSerialAsync> bus(ID);

// BME280 sensor instances with settings
BME280I2C_BRZO::Settings settings_bme_0;
BME280I2C_BRZO bme_0;
BME280I2C_BRZO::Settings settings_bme_1;
BME280I2C_BRZO bme_1;

// sensor struct
struct sensor
{
  uint16_t humidity;
  uint16_t temperature;
  bool connected_0;
  bool connected_1;
};
// complete record
struct sensor_record
{
  sensor sensors[MAX_WIRES];
};
// prefill record instance
sensor_record record = {.sensors = {{.humidity = 0, .temperature = 0, .connected_0 = false, .connected_1 = false}, {.humidity = 0, .temperature = 0, .connected_0 = false, .connected_1 = false}, {.humidity = 0, .temperature = 0, .connected_0 = false, .connected_1 = false}}};

/**
 * Selects a sensor wire.
 */
void tca_select(uint8_t i)
{
  if (i > 7)
    return;

  uint8_t buffer[1];
  brzo_i2c_start_transaction(TCAADDR, 400);
  buffer[0] = 1 << i;
  brzo_i2c_write(buffer, 1, false);
  uint8_t result = brzo_i2c_end_transaction();

#ifdef DEBUG
  if (result != 0)
  {
    Serial.printf("tca select result: %d\n", result);
  }
#endif
}

/**
 * Detects the first or second sensors on given wire index.
 * 
 * If sensor was already detected, the sensor is only validated and not initialized.
 */
void detect_sensor(uint8_t index, bool first)
{
  if (first)
  {
    record.sensors[index].connected_0 = record.sensors[index].connected_0 ? bme_0.sensorPresent() : bme_0.begin();
#ifdef DEBUG
    if (!record.sensors[index].connected_0)
    {
      Serial.printf("Could not find BME280 sensor (0) for connector #%d\n", index);
    }
#endif
  }
  else
  {
    record.sensors[index].connected_1 = record.sensors[index].connected_1 ? bme_1.sensorPresent() : bme_1.begin();
#ifdef DEBUG
    if (!record.sensors[index].connected_1)
    {
      Serial.printf("Could not find BME280 sensor (1) for connector #%d\n", index);
    }
#endif
  }
}

/**
 * Reads a complete sensor record and sends them to peer.
 */
void read_and_send_record()
{
  for (uint8_t i = 0; i < MAX_WIRES; i++)
  {
    // select wire
    tca_select(i);

    uint8_t count = 0;
    record.sensors[i].humidity = 0;
    record.sensors[i].temperature = 0;

    // detect sensor before reading
    detect_sensor(i, true);
    if (record.sensors[i].connected_0)
    {
      record.sensors[i].humidity += bme_0.hum() * 100;
      record.sensors[i].temperature += bme_0.temp() * 100;
      count++;
    }
    // detect sensor before reading
    detect_sensor(i, false);
    if (record.sensors[i].connected_1)
    {
      record.sensors[i].humidity += bme_1.hum() * 100;
      record.sensors[i].temperature += bme_1.temp() * 100;
      count++;
    }
    // calculate average value for transmission, if 2 sensors are readed for ech wire
    if (count > 0)
    {
      record.sensors[i].humidity = record.sensors[i].humidity / count;
      record.sensors[i].temperature = record.sensors[i].temperature / count;
    }
  }

#ifdef DEBUG
  for (uint8_t i = 0; i < MAX_WIRES; i++)
  {
    Serial.printf("Payload: hum %u; temp %u; s0 %u; s1 %u\n", record.sensors[i].humidity, record.sensors[i].temperature, record.sensors[i].connected_0, record.sensors[i].connected_1);
  }
#endif

  // send dara
  bus.send(45, &record, sizeof(record));
}

// error handler for PJON
void error_handler(uint8_t code, uint16_t data, void *custom_pointer)
{
#ifdef DEBUG
  Serial.printf("PJON error: %d\n", code);
#endif
}

/**
 * Setup system.
 */
void setup()
{
  delay(2000);
#ifdef DEBUG
  Serial.begin(9600, SERIAL_8N1);
  Serial.println("\nInit.");
#endif

  // setup I2C bus with 2ms timeout
  brzo_i2c_setup(SDA, SCL, 2000);

  // setup BME280 instances
  // set correct address for different instances
  settings_bme_0.bme280Addr = BME280I2C::I2CAddr_0x76;
  bme_0.setSettings(settings_bme_0);
  settings_bme_1.bme280Addr = BME280I2C::I2CAddr_0x77;
  bme_1.setSettings(settings_bme_1);

  // start software serial port
  port.begin(9600, SWSERIAL_8N1, RX_PIN, TX_PIN, false);

  // setup PJON with serial port
  bus.strategy.set_serial(&port);
  // set error handler
  bus.set_error(error_handler);
  // start bus
  bus.begin();

  // detect sensor initially
  for (uint8_t i = 0; i < MAX_WIRES; i++)
  {
    tca_select(i);
    detect_sensor(i, true);
    detect_sensor(i, false);
  }

#ifdef DEBUG
  Serial.println("\nInit done.");
#endif
}

/**
 * Event loop.
 */
void loop()
{
  if ((millis() - lastTime) > CHECK_INTERVAL)
  {
    // read sensors after interval is over
    read_and_send_record();
    // store last submission
    lastTime = millis();
  }
  // trigger PJON handlers
  bus.update();
  bus.receive();
}

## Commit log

2020-04-10 use brzo i2c implementation
2020-04-20 back to ubidots, finalize work
    * reduce buffer for softwareserial
    * auto reconnect for mqtt
    * fixed versions
    [main.cpp]
2020-04-21 add wiring for sensor unit
2020-04-21 add control unit wiring
    [control_unit.fzz, sensor_unit.fzz]
2020-04-22 fix message size and timeout of sensor data
    [main.cpp]
2020-05-01 do not restart if initial connection failed
    [main.cpp]
